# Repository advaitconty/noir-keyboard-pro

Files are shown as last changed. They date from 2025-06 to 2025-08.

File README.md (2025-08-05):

# Noir Keyboard Pro
A keyboard designed around the iPad Pro 11inch, mainly for use on the side

## Features
- Choc Red Pro switches that are hotswappable to your heart's content
- A simple design with extra pins if anything extra is required for a Pico
- A stabilizer-less design allowing for just nice uses

## BOM
*Prices in USD*

|Item |Quantity|Full Price|Remarks |Link |
|---|---|---|---|---|
|EVA foam |1 |$1.29 |Black variant 3mm 30x50  |https://www.lazada.sg/products/eva-foam-board-production-1-10mm-thick-foam-board-i2849696182-s19642596230.html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 |
|Rasperry Pi Pico H |1 |$15.52 | |https://www.lazada.sg/products/original-raspberry-pi-pico-2-pico-with-wireless-wifi-development-boardpico-or-pico-h-with-pin-header-support-mciropythonc-i3197404377-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 |
|Micro-USB to USB-C cable |1 |$3.87 | |https://www.lazada.sg/products/pdp-i1856449135-s9890909408.html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|
|Kailh Choc Red Pro Switches (v1) |100 |$41.15 |x90 piece |https://www.lazada.sg/products/kailh-low-profile-choc-switch-1350-rgb-for-keyboard-crystal-red-pro-pale-blue-pink-robin-silver-brown-white-yellow-orange-i3235755317-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 |
|Schotky Diodes |100 |$4.58 |x100 piece |https://www.lazada.sg/products/1n4148-do-35-small-signal-fast-switching-diode-i2668535659-s17380791247.html? |
|Kailh Choc Hotswap Socket |100 |$13.97 |x90 piece |https://www.lazada.sg/products/kailh-hot-swap-plug-socket-for-kailh-low-profile-switch-choc-1350-i3216869960-s21821088673.html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 |
|Noir Keyboard Pro PCB from JLCPCB |5 |$15.70 |Purchased |NA |
|128x32 OLED Screen |1 |$0.64 |White variant |https://www.lazada.sg/products/pdp-i3161600227-s21505742950.html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 |
|Shipping label |1 |$2.87 |For 3D printed parts |https://www.singpost.com/send-receive/sending-within-singapore/postage-paid-packaging/smartpac |
|Chisel tip for pinecil (my pinecil tip doesn't work - tried everything including steel wool)|1 |$8.58 |For my broken pinecil tip + getting D24 variant|https://www.lazada.sg/products/pine64-ts100-ts101-soldering-iron-tips-replacement-various-models-of-pinecil-v2-electric-soldering-iron-tip-ts-series-bc2-ils-k-i34779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 |
|Female headers for pico + display |2 |$1.46 |1x 20 pin + 1x 4 pin |https://www.lazada.sg//products/i2845738229-s19616005484.html?spm=a2o42.cart.0.0.732e7a93AmAcCy&urlFlag=true |
|Shipping Fees for everything |1 |$15 | |NA |

*Total: USD123.17 (SGD158.59)*

## Photos in CAD

*PCB*


*KiCad Schematic*


*Case design*


*Keycaps*


Full design of everything
---

## Credits
Massive kudos to @joe-scotto's ScottoKeebs repo (KiCad Footprints from the "Extras" folder, keyswitch design roughly taken from him)
Shapr3D and KiCad for their wonderful software

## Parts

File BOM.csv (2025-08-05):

Parts List (all prices in USD)
Total | $123.17
Ordering | Item | Quantity | Full Price | Remarks | Link
TRUE | EVA foam | 1 | $1.29 | Black variant 3mm 30x50 | https://www.lazada.sg/products/eva-foam-board-production-1-10mm-thick-foam-board-i2849696182-s19642596230.html
TRUE | Rasperry Pi Pico H | 1 | $15.52 |  | https://www.lazada.sg/products/original-raspberry-pi-pico-2-pico-with-wireless-wifi-development-boardpico-or-pico-h-with-pin-header-support-mciropythonc-i3197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
TRUE | Micro-USB to USB-C cable | 1 | $3.87 |  | https://www.lazada.sg/products/pdp-i1856449135-s9890909408.html?c=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
TRUE | Kailh Choc Red Pro Switches (v1) | 100 | $41.15 | x90 piece | https://www.lazada.sg/products/kailh-low-profile-choc-switch-1350-rgb-for-keyboard-crystal-red-pro-pale-blue-pink-robin-silver-brown-white-yellow-orange-i3235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
TRUE | Schotky Diodes | 100 | $4.58 | x100 piece | https://www.lazada.sg/products/1n4148-do-35-small-signal-fast-switching-diode-i2668535659-s17380791247.html
TRUE | Kailh Choc Hotswap Socket | 100 | $13.97 | x90 piece | https://www.lazada.sg/products/kailh-hot-swap-plug-socket-for-kailh-low-profile-switch-choc-1350-i3216869960-s21821088673.html
TRUE | Noir Keyboard Pro PCB from JLCPCB | 5 | $15.70 | Purchased | NA
TRUE | 128x32 OLED Screen | 1 | $0.64 | White variant | https://www.lazada.sg/products/pdp-i3161600227-s21505742950.html?c=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
TRUE | Shipping label | 1 | $2.87 | For 3D printed parts | https://www.singpost.com/send-receive/sending-within-singapore/postage-paid-packaging/smartpac
TRUE | Chisel tip for pinecil (my pinecil tip doesn't work - tried everything including steel wool) | 1 | $8.58 | For my broken pinecil tip + getting D24 variant | https://www.lazada.sg/products/pine64-ts100-ts101-soldering-iron-tips-replacement-various-models-of-pinecil-v2-electric-soldering-iron-tip-ts-series-bc2-ils-k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
TRUE | Female headers for pico + display | 2 | $1.46 | 1x 20 pin + 1x 4 pin | https://www.lazada.sg//products/i2845738229-s19616005484.html?urlFlag=true
TRUE | Shipping Fees for everything | 1 | $15 |  | NA

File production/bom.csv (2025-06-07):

Designator | Footprint | Quantity | Value | LCSC Part #
'"1, -_1, /1, 0)1, 1!1, 2@1, 3#1, 4$1, 5%1, 6^1, 7&1, 8*1, 9(1, ;:1, <,1, =+1, >.1, A1, B1, BACKSPACE1, BACKSPACE2, C1, CMD1, CMD2, CONTROL1, D1, DEL1, DEL2, DOWN1, E1, ENTER1, ESC1, F1, F10, F11, F12, F13, F2, F3, F4, F5, F6, F7, F8, F9, FN1, G1, H1, I1, J1, K1, L1, LEFT1, M1, N1, O1, OPTION1, P1, Q1, R1, RIGHT1, S1, SHIFT4, T1, U2, UP1, V1, W1, X1, Y1, Z1, [{1, ]}1, `~1 | Hotswap_Choc_V1_1.00u | 74 | Keyswitch
'"DIODE1, -_DIODE1, /?DIODE1, 0)DIODE1, 1!DIODE1, 2@DIODE1, 3#DIODE1, 4$DIODE1, 5%DIODE1, 6^DIODE1, 7&DIODE1, 8*DIODE1, 9(DIODE1, ;:DIODE1, <,DIODE1, =+DIODE1, >.DIODE1, ADIODE1, BACKSPACEDIODE1, BACKSPACEDIODE2, BDIODE1, CAPSLOCKDIODE1, CDIODE1, CMDDIODE1, CMDDIODE2, CONTROLDIODE1, DDIODE1, DELDIODE1, DELDIODE2, DOWNDIODE1, EDIODE1, ENTERDIODE1, ENTERDIODE2, ESCDIODE1, F10DIODE1, F11DIODE1, F12DIODE1, F1DIODE1, F2DIODE1, F3DIODE1, F4DIODE1, F5DIODE1, F6DIODE1, F7DIODE1, F8DIODE1, F9DIODE1, FDIODE1, FNDIODE1, GDIODE1, HDIODE1, IDIODE1, JDIODE1, KDIODE1, LDIODE1, LEFTDIODE1, MDIODE1, NDIODE1, ODIODE1, OPTIONDIODE1, PDIODE1, QDIODE1, RDIODE1, RIGHTDIODE1, SDIODE1, SHIFTDIODE1, SHIFTDIODE2, SHIFTDIODE3, SHIFTDIODE4, SPACEDIODE1, SPACEDIODE2, SPACEDIODE3, SPACEDIODE4, TABDIODE1, TDIODE1, UDIODE1, UPDIODE1, VDIODE1, WDIODE1, XDIODE1, YDIODE1, ZDIODE1, [{DIODE1, \|DIODE1, ]}DIODE1, `~DIODE1 | Diode_DO-35 | 85 | Diode
CAPSLOCK1 | Hotswap_Choc_V1_1.75u | 1 | Keyswitch
ENTER2, SHIFT1, SHIFT2 | Hotswap_Choc_V1_1.25u | 3 | Keyswitch
SHIFT3, SPACE1, SPACE2, SPACE3, SPACE4, TAB1, \|1 | Hotswap_Choc_V1_1.50u | 7 | Keyswitch
U1 | Raspberry_Pi_Pico | 1 | Raspberry_Pi_Pico

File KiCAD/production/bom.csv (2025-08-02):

Designator | Footprint | Quantity | Value | LCSC Part #
'"DIODE1, -_DIODE1, /?DIODE1, 0)DIODE1, 1!DIODE1, 2@DIODE1, 3#DIODE1, 4$DIODE1, 5%DIODE1, 6^DIODE1, 7&DIODE1, 8*DIODE1, 9(DIODE1, ;:DIODE1, <,DIODE1, =+DIODE1, >.DIODE1, ADIODE1, BACKSPACEDIODE1, BACKSPACEDIODE2, BDIODE1, CAPSLOCKDIODE1, CDIODE1, CMDDIODE1, CMDDIODE2, CONTROLDIODE1, DDIODE1, DELDIODE1, DELDIODE2, DOWNDIODE1, EDIODE1, ENTERDIODE1, ENTERDIODE2, ESCDIODE1, F10DIODE1, F11DIODE1, F12DIODE1, F1DIODE1, F2DIODE1, F3DIODE1, F4DIODE1, F5DIODE1, F6DIODE1, F7DIODE1, F8DIODE1, F9DIODE1, FDIODE1, FNDIODE1, GDIODE1, HDIODE1, IDIODE1, JDIODE1, KDIODE1, LDIODE1, LEFTDIODE1, MDIODE1, NDIODE1, ODIODE1, OPTIONDIODE1, PDIODE1, QDIODE1, RDIODE1, RIGHTDIODE1, SDIODE1, SHIFTDIODE1, SHIFTDIODE2, SHIFTDIODE3, SHIFTDIODE4, SPACEDIODE1, SPACEDIODE2, SPACEDIODE3, SPACEDIODE4, TABDIODE1, TDIODE1, UDIODE1, UPDIODE1, VDIODE1, WDIODE1, XDIODE1, YDIODE1, ZDIODE1, [{DIODE1, \|DIODE1, ]}DIODE1, `~DIODE1 | Diode_DO-35 | 85 | Diode
A, ALT/OPTION, ANGLE BRACKET, B, BACKSPACE, BLANK BACKSPACE, BLANK DELETE, BLANK ENTER, C, CHEVRON, CLOSED SQ. BRACKET, CONTROL, D, DASH, DELETE, DOWN ARROW, E, EIGHT, EQUALS, ESCAPE, F, F1, F10, F11, F12, F2, F3, F4, F5, F6, F7, F8, F9, FIVE, FOUR, FUNCTION, G, H, I, J, K, L, LEFT ARROW, M, N, NINE, O, ONE, OPEN SQ. BRACKET, P, Q, QUOTES, R, RIGHT, S, SEMI-COLON, SEVEN, SHIFT, SIX, SLASH, SUPER/COMMAND_2, SUPER/COMMAND, T, THREE, TILDE, TWO, U, UP ARROW, V, W, X, Y, Z, ZERO | Hotswap_Choc_V1_1.00u | 74 | Keyswitch
BACKSLASH, BLANK SHIFT, SPACE_4, SPACE_3, SPACE_2, SPACE, TAB | Hotswap_Choc_V1_1.50u | 7 | Keyswitch
BLANK SHIFT_2, ENTER, SHIFT_2 | Hotswap_Choc_V1_1.25u | 3 | Keyswitch
CAPS LOCK | Hotswap_Choc_V1_1.75u | 1 | Keyswitch
J2 | OLED_128x32 | 1 | OLED_128x32
U1 | Raspberry_Pi_Pico | 1 | Raspberry_Pi_Pico

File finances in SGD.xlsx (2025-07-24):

Parts List (all prices in SGD) |  | #VALUE!
Total | $104.32 | Budget: $191.58
Ordering | Item | Quantity | Price | Remarks | Link
TRUE | 5mm Thick EVA Foam | 1.00 | $3.90 |  | https://www.aliexpress.com/item/1005002621956105.html?mp=1
TRUE | Rasperry Pi Pico (With USB-C) | 1.00 | $2.88 |  | https://www.aliexpress.com/item/1005003371056277.html?mp=1
TRUE | Micro-USB to USB-C cable (in case Pico doesn't fit) | 1.00 | $2.50 |  | https://www.aliexpress.com/item/1005002361842974.html?mp=1
TRUE | Kailh Choc Red Pro Switches (v1) | 100.00 | $58.91 | Ordering x2 (1 90 piece, 1x 10 piece) | https://www.aliexpress.com/item/1005006626760418.html?mp=1
TRUE | Schotky Diodes | 100.00 | $1.31 | Sold in packs of 100 | https://www.aliexpress.com/item/1005008067721732.html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
TRUE | Kailh Choc Hotswap Socket | 100.00 | $7.05 | Sold in packs of 100 | https://www.aliexpress.com/item/1005006625852715.html?mp=1
TRUE | Noir Keyboard Pro PCB from JLCPCB | 5.00 | $27.77 | Sold in packs of 5, with shipping + new customer discount coupon | NA
FALSE | Silent Ambient Twilight Choc v1 Switches | 100.00 | $124.20 | Sold in packs of 10, considering between Choc Red Pros | https://ergokeyboard.sg/products/ambients-twilight-silent-linear-choc-switches
TRUE | 128x32 OLED Screen | 1.00 | $2.44 | White variant | https://www.aliexpress.com/item/1005006351390199.html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

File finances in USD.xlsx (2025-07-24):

Parts List (all prices in USD)
Total | $83.68
Ordering | Item | Quantity | Price | Remarks | Link
TRUE | 5mm Thick EVA Foam | 1.00 | $3.06 |  | https://www.aliexpress.com/item/1005002621956105.html?mp=1
TRUE | Rasperry Pi Pico (With USB-C) | 1.00 | $2.26 |  | https://www.aliexpress.com/item/1005003371056277.html?mp=1
TRUE | Micro-USB to USB-C cable (in case Pico doesn't fit) | 1.00 | $1.96 |  | https://www.aliexpress.com/item/1005002361842974.html?mp=1
TRUE | Kailh Choc Red Pro Switches (v1) | 100.00 | $46.16 | Ordering x2 (1 90 piece, 1x 10 piece) | https://www.aliexpress.com/item/1005006626760418.html?mp=1
TRUE | Schotky Diodes | 100.00 | $1.03 | Sold in packs of 100 | https://www.aliexpress.com/item/1005008067721732.html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
TRUE | Kailh Choc Hotswap Socket | 100.00 | $5.53 | Sold in packs of 100 | https://www.aliexpress.com/item/1005006625852715.html?mp=1
TRUE | Noir Keyboard Pro PCB from JLCPCB | 5.00 | $21.77 | Sold in packs of 5, with shipping + new customer discount coupon | NA
TRUE | 128x32 OLED Screen | 1.00 | $1.91 | White variant | https://www.aliexpress.com/item/1005006351390199.html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

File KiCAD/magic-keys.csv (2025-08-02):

Id | Designator | Footprint | Quantity | Designation | Supplier and ref
1 | Up1,Cmd1,Del1,Backspace1,'1,Option1,Q1,5%1,1!1,/1,-_1,F13,Control1,S1,F5,U2,6^1,Cmd2,H1,L1,E1,F6,B1,Enter1,Left1,M1, | :1,N1,F10,P1,F1,K1,7&1,<,1,`~1,=+1,F8,2@1,8*1,Backspace2,D1,3#1,Esc1,F2,Del2,T1,G1,X1,0)1,>.1,F4,F3,J1,Down1,O1,W1,9(1,V1,F9,C1,F7,A1,Right1,Fn1,[{1,I1,F11,Y1,R1,Shift4,F12,Z1,]}1,4$1" | Hotswap_Choc_V1_1.00u | 74 | Keyswitch
2 | J2 | OLED_128x32 | 1 | OLED_128x32
3 | Enter2,Shift1,Shift2 | Hotswap_Choc_V1_1.25u | 3 | Keyswitch
4 | U1 | Raspberry_Pi_Pico | 1 | Raspberry_Pi_Pico
5 | Space3,Tab1,Space4,Space1,\|1,Space2,Shift3 | Hotswap_Choc_V1_1.50u | 7 | Keyswitch
6 | CapsLock1 | Hotswap_Choc_V1_1.75u | 1 | Keyswitch
7 | IDiode1,>.Diode1,[{Diode1,`~Diode1,EnterDiode1,NDiode1,ShiftDiode3,=+Diode1,UDiode1,SpaceDiode1,QDiode1,1!Diode1,0)Diode1,PDiode1,DelDiode2,5%Diode1,SDiode1,SpaceDiode4,BackspaceDiode1,F9Diode1,EDiode1,ControlDiode1,ShiftDiode2,F10Diode1,F3Diode1,ShiftDiode1,EscDiode1,HDiode1,LDiode1,VDiode1,F6Diode1,KDiode1,BackspaceDiode2,TDiode1,MDiode1,F1Diode1,FnDiode1,ShiftDiode4,F7Diode1,XDiode1,WDiode1,DDiode1,9(Diode1,3#Diode1,6^Diode1,2@Diode1,F4Diode1,F12Diode1,F5Diode1,8*Diode1,/?Diode1,CmdDiode1,CapsLockDiode1,DownDiode1,LeftDiode1,F11Diode1,SpaceDiode2,UpDiode1,SpaceDiode3,DelDiode1,CmdDiode2,OptionDiode1,ODiode1,TabDiode1,ADiode1,4$Diode1,F2Diode1,RDiode1,'Diode1,YDiode1,EnterDiode2,GDiode1,<,Diode1,ZDiode1,JDiode1,F8Diode1,7&Diode1,RightDiode1,]}Diode1,FDiode1, | :Diode1,-_Diode1,BDiode1,CDiode1,\|Diode1" | Diode_DO-35 | 85 | Diode

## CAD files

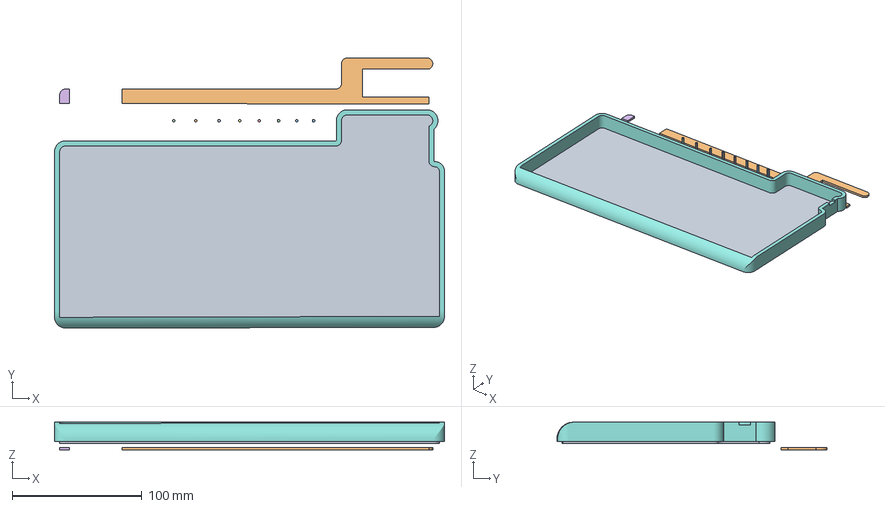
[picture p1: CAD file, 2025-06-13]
3D Files/Case/Print Ready Case.3mf
301.0 x 208.5 x 21.4 mm

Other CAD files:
3D Files/Full Design.step
3D Files/PCB.step

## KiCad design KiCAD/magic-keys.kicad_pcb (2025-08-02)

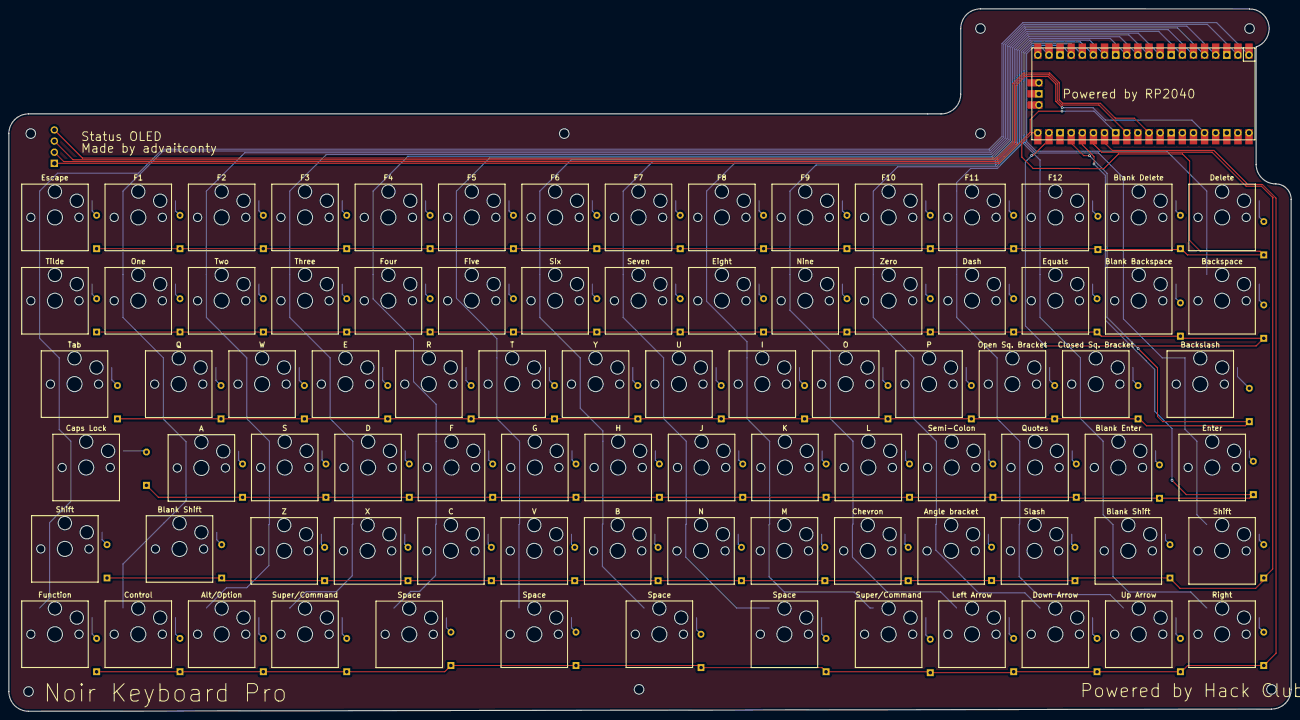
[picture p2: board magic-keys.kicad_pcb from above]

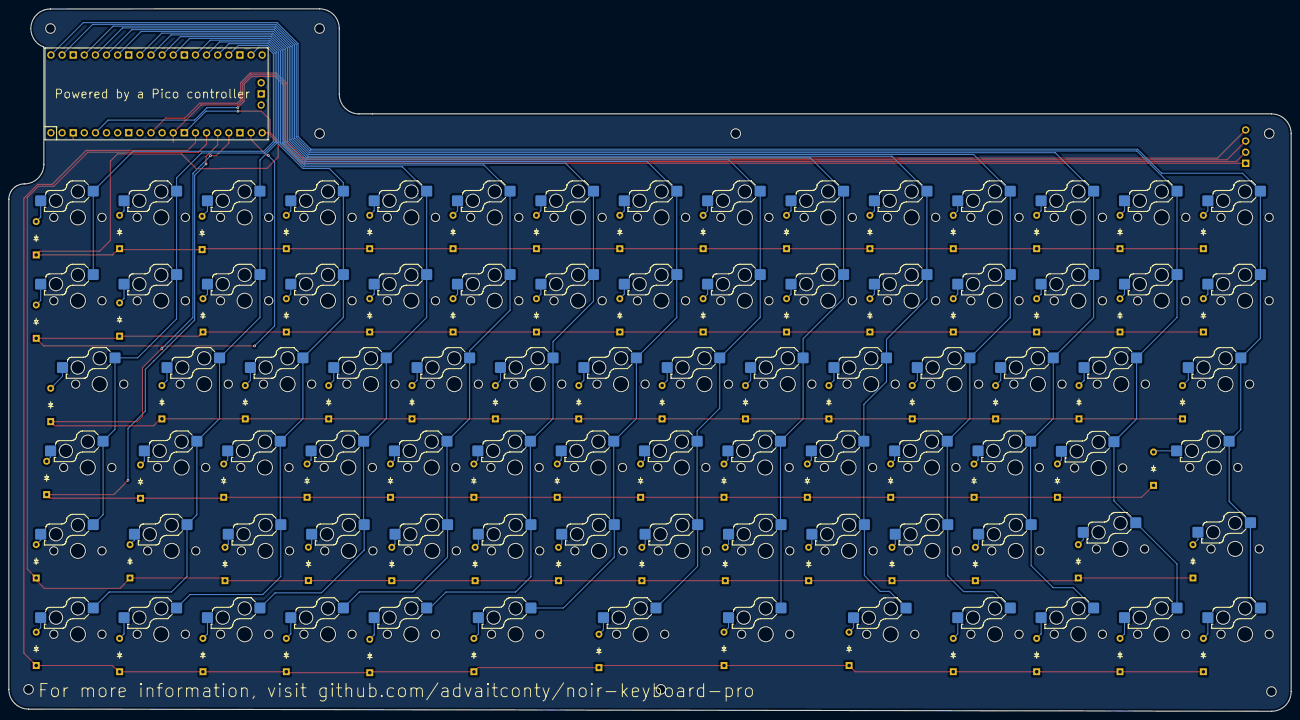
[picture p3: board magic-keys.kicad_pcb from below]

Board: 2 copper layers, 293.0 x 160.5 mm, 172 parts (85 on the bottom side), 110 nets.

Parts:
0)Diode1, 1!Diode1, 2@Diode1, 3#Diode1, 4$Diode1, 5%Diode1, 6^Diode1, 7&Diode1, 8*Diode1, 9(Diode1: Diode; Diode_DO-35
'"Diode1: Diode; Diode_DO-35
-_Diode1: Diode; Diode_DO-35
/?Diode1: Diode; Diode_DO-35
;:Diode1: Diode; Diode_DO-35
<,Diode1: Diode; Diode_DO-35
=+Diode1: Diode; Diode_DO-35
>.Diode1: Diode; Diode_DO-35
A: Keyswitch; Hotswap_Choc_V1_1.00u
ADiode1: Diode; Diode_DO-35
Alt/Option: Keyswitch; Hotswap_Choc_V1_1.00u
Angle bracket: Keyswitch; Hotswap_Choc_V1_1.00u
B: Keyswitch; Hotswap_Choc_V1_1.00u
BDiode1: Diode; Diode_DO-35
Backslash: Keyswitch; Hotswap_Choc_V1_1.50u
Backspace: Keyswitch; Hotswap_Choc_V1_1.00u
BackspaceDiode1, BackspaceDiode2: Diode; Diode_DO-35
Blank Backspace: Keyswitch; Hotswap_Choc_V1_1.00u
Blank Delete: Keyswitch; Hotswap_Choc_V1_1.00u
Blank Enter: Keyswitch; Hotswap_Choc_V1_1.00u
Blank Shift: Keyswitch; Hotswap_Choc_V1_1.25u
Blank Shift#2: Keyswitch; Hotswap_Choc_V1_1.50u
C: Keyswitch; Hotswap_Choc_V1_1.00u
CDiode1: Diode; Diode_DO-35
Caps Lock: Keyswitch; Hotswap_Choc_V1_1.75u
CapsLockDiode1: Diode; Diode_DO-35
Chevron: Keyswitch; Hotswap_Choc_V1_1.00u
Closed Sq. Bracket: Keyswitch; Hotswap_Choc_V1_1.00u
CmdDiode1, CmdDiode2: Diode; Diode_DO-35
Control: Keyswitch; Hotswap_Choc_V1_1.00u
ControlDiode1: Diode; Diode_DO-35
D: Keyswitch; Hotswap_Choc_V1_1.00u
DDiode1: Diode; Diode_DO-35
Dash: Keyswitch; Hotswap_Choc_V1_1.00u
DelDiode1, DelDiode2: Diode; Diode_DO-35
Delete: Keyswitch; Hotswap_Choc_V1_1.00u
Down Arrow: Keyswitch; Hotswap_Choc_V1_1.00u
DownDiode1: Diode; Diode_DO-35
E: Keyswitch; Hotswap_Choc_V1_1.00u
EDiode1: Diode; Diode_DO-35
Eight: Keyswitch; Hotswap_Choc_V1_1.00u
Enter: Keyswitch; Hotswap_Choc_V1_1.25u
EnterDiode1, EnterDiode2: Diode; Diode_DO-35
Equals: Keyswitch; Hotswap_Choc_V1_1.00u
EscDiode1: Diode; Diode_DO-35
Escape: Keyswitch; Hotswap_Choc_V1_1.00u
F, F1, F2, F3, F4, F5, F6, F7, F8, F9, F10, F11, F12: Keyswitch; Hotswap_Choc_V1_1.00u
F1Diode1, F2Diode1, F3Diode1, F4Diode1, F5Diode1, F6Diode1, F7Diode1, F8Diode1, F9Diode1, F10Diode1, F11Diode1, F12Diode1: Diode; Diode_DO-35
FDiode1: Diode; Diode_DO-35
Five: Keyswitch; Hotswap_Choc_V1_1.00u
FnDiode1: Diode; Diode_DO-35
Four: Keyswitch; Hotswap_Choc_V1_1.00u
Function: Keyswitch; Hotswap_Choc_V1_1.00u
G: Keyswitch; Hotswap_Choc_V1_1.00u
GDiode1: Diode; Diode_DO-35
H: Keyswitch; Hotswap_Choc_V1_1.00u
HDiode1: Diode; Diode_DO-35
I: Keyswitch; Hotswap_Choc_V1_1.00u
IDiode1: Diode; Diode_DO-35
J: Keyswitch; Hotswap_Choc_V1_1.00u
J2: OLED_128x32
JDiode1: Diode; Diode_DO-35
K: Keyswitch; Hotswap_Choc_V1_1.00u
KDiode1: Diode; Diode_DO-35
L: Keyswitch; Hotswap_Choc_V1_1.00u
LDiode1: Diode; Diode_DO-35
Left Arrow: Keyswitch; Hotswap_Choc_V1_1.00u
LeftDiode1: Diode; Diode_DO-35
M: Keyswitch; Hotswap_Choc_V1_1.00u
MDiode1: Diode; Diode_DO-35
N: Keyswitch; Hotswap_Choc_V1_1.00u
NDiode1: Diode; Diode_DO-35
Nine: Keyswitch; Hotswap_Choc_V1_1.00u
O: Keyswitch; Hotswap_Choc_V1_1.00u
ODiode1: Diode; Diode_DO-35
One: Keyswitch; Hotswap_Choc_V1_1.00u
Open Sq. Bracket: Keyswitch; Hotswap_Choc_V1_1.00u
OptionDiode1: Diode; Diode_DO-35
P: Keyswitch; Hotswap_Choc_V1_1.00u
PDiode1: Diode; Diode_DO-35
Q: Keyswitch; Hotswap_Choc_V1_1.00u
QDiode1: Diode; Diode_DO-35
Quotes: Keyswitch; Hotswap_Choc_V1_1.00u
R: Keyswitch; Hotswap_Choc_V1_1.00u
RDiode1: Diode; Diode_DO-35
Right: Keyswitch; Hotswap_Choc_V1_1.00u
RightDiode1: Diode; Diode_DO-35
S: Keyswitch; Hotswap_Choc_V1_1.00u
SDiode1: Diode; Diode_DO-35
Semi-Colon: Keyswitch; Hotswap_Choc_V1_1.00u
Seven: Keyswitch; Hotswap_Choc_V1_1.00u
Shift: Keyswitch; Hotswap_Choc_V1_1.25u
Shift#2: Keyswitch; Hotswap_Choc_V1_1.00u
ShiftDiode1, ShiftDiode2, ShiftDiode3, ShiftDiode4: Diode; Diode_DO-35
Six: Keyswitch; Hotswap_Choc_V1_1.00u
Slash: Keyswitch; Hotswap_Choc_V1_1.00u
Space: Keyswitch; Hotswap_Choc_V1_1.50u
Space#2, Space#3, Space#4: Keyswitch; Hotswap_Choc_V1_1.50u
SpaceDiode1, SpaceDiode2, SpaceDiode3, SpaceDiode4: Diode; Diode_DO-35
Super/Command: Keyswitch; Hotswap_Choc_V1_1.00u
Super/Command#2: Keyswitch; Hotswap_Choc_V1_1.00u
T: Keyswitch; Hotswap_Choc_V1_1.00u
TDiode1: Diode; Diode_DO-35
Tab: Keyswitch; Hotswap_Choc_V1_1.50u
TabDiode1: Diode; Diode_DO-35
Three: Keyswitch; Hotswap_Choc_V1_1.00u
Tilde: Keyswitch; Hotswap_Choc_V1_1.00u
Two: Keyswitch; Hotswap_Choc_V1_1.00u
U: Keyswitch; Hotswap_Choc_V1_1.00u
U1: Raspberry_Pi_Pico
UDiode1: Diode; Diode_DO-35
Up Arrow: Keyswitch; Hotswap_Choc_V1_1.00u
UpDiode1: Diode; Diode_DO-35
V: Keyswitch; Hotswap_Choc_V1_1.00u
VDiode1: Diode; Diode_DO-35
W: Keyswitch; Hotswap_Choc_V1_1.00u
WDiode1: Diode; Diode_DO-35
X: Keyswitch; Hotswap_Choc_V1_1.00u
XDiode1: Diode; Diode_DO-35
Y: Keyswitch; Hotswap_Choc_V1_1.00u
YDiode1: Diode; Diode_DO-35
Z: Keyswitch; Hotswap_Choc_V1_1.00u
ZDiode1: Diode; Diode_DO-35
Zero: Keyswitch; Hotswap_Choc_V1_1.00u
[{Diode1: Diode; Diode_DO-35
\|Diode1: Diode; Diode_DO-35
]}Diode1: Diode; Diode_DO-35
`~Diode1: Diode; Diode_DO-35

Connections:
Column 0: Caps Lock.1, Escape.1, Function.1, Shift.1, Tab.1, Tilde.1, U1.1 (GPIO0)
Column 1: A.1, Blank Shift#2.1, Control.1, F1.1, One.1, Q.1, U1.2 (GPIO1)
Column 2: Alt/Option.1, F2.1, S.1, Two.1, U1.4 (GPIO2), W.1, Z.1
Column 3: D.1, E.1, F3.1, Super/Command.1, Three.1, U1.5 (GPIO3), X.1
Column 4: C.1, F.1, F4.1, Four.1, R.1, Space#3.1, U1.6 (GPIO4)
Column 5: F5.1, Five.1, G.1, Space#4.1, T.1, U1.7 (GPIO5), V.1
Column 6: B.1, F6.1, H.1, Six.1, Space.1, U1.9 (GPIO6), Y.1
Column 7: F7.1, J.1, N.1, Seven.1, Space#2.1, U.1, U1.10 (GPIO7)
Column 8: Eight.1, F8.1, I.1, K.1, M.1, Super/Command#2.1, U1.11 (GPIO8)
Column 9: Chevron.1, F9.1, L.1, Left Arrow.1, Nine.1, O.1, U1.12 (GPIO9)
Column 10: Angle bracket.1, Down Arrow.1, F10.1, P.1, Semi-Colon.1, U1.14 (GPIO10), Zero.1
Column 11: Dash.1, F11.1, Open Sq. Bracket.1, Quotes.1, Slash.1, U1.15 (GPIO11), Up Arrow.1
Column 12: Blank Enter.1, Blank Shift.1, Closed Sq. Bracket.1, Equals.1, F12.1, Right.1, U1.16 (GPIO12)
Column 13: Backslash.1, Blank Backspace.1, Blank Delete.1, Enter.1, Shift#2.1, U1.17 (GPIO13)
Column 14: Backspace.1, Delete.1, U1.19 (GPIO14)
unnamed: 0)Diode1.2 (A), Zero.2
unnamed: 1!Diode1.2 (A), One.2
unnamed: 2@Diode1.2 (A), Two.2
unnamed: 3#Diode1.2 (A), Three.2
unnamed: 4$Diode1.2 (A), Four.2
unnamed: 5%Diode1.2 (A), Five.2
unnamed: 6^Diode1.2 (A), Six.2
unnamed: 7&Diode1.2 (A), Seven.2
unnamed: 8*Diode1.2 (A), Eight.2
unnamed: 9(Diode1.2 (A), Nine.2
unnamed: '"Diode1.2 (A), Quotes.2
unnamed: -_Diode1.2 (A), Dash.2
unnamed: /?Diode1.2 (A), Slash.2
unnamed: ;:Diode1.2 (A), Semi-Colon.2
unnamed: <,Diode1.2 (A), Chevron.2
unnamed: =+Diode1.2 (A), Equals.2
unnamed: >.Diode1.2 (A), Angle bracket.2
unnamed: A.2, ADiode1.2 (A)
unnamed: B.2, BDiode1.2 (A)
unnamed: BackspaceDiode1.2 (A), Blank Backspace.2
unnamed: Backspace.2, BackspaceDiode2.2 (A)
unnamed: C.2, CDiode1.2 (A)
unnamed: Caps Lock.2, CapsLockDiode1.2 (A)
unnamed: CmdDiode1.2 (A), Super/Command.2
unnamed: CmdDiode2.2 (A), Super/Command#2.2
unnamed: Control.2, ControlDiode1.2 (A)
unnamed: D.2, DDiode1.2 (A)
unnamed: Blank Delete.2, DelDiode1.2 (A)
unnamed: DelDiode2.2 (A), Delete.2
unnamed: Down Arrow.2, DownDiode1.2 (A)
unnamed: E.2, EDiode1.2 (A)
unnamed: Blank Enter.2, EnterDiode1.2 (A)
unnamed: Enter.2, EnterDiode2.2 (A)
unnamed: EscDiode1.2 (A), Escape.2
unnamed: F1.2, F1Diode1.2 (A)
unnamed: F2.2, F2Diode1.2 (A)
unnamed: F3.2, F3Diode1.2 (A)
unnamed: F4.2, F4Diode1.2 (A)
unnamed: F5.2, F5Diode1.2 (A)
unnamed: F6.2, F6Diode1.2 (A)
unnamed: F7.2, F7Diode1.2 (A)
unnamed: F8.2, F8Diode1.2 (A)
unnamed: F9.2, F9Diode1.2 (A)
unnamed: F10.2, F10Diode1.2 (A)
unnamed: F11.2, F11Diode1.2 (A)
unnamed: F12.2, F12Diode1.2 (A)
unnamed: F.2, FDiode1.2 (A)
unnamed: FnDiode1.2 (A), Function.2
unnamed: G.2, GDiode1.2 (A)
unnamed: H.2, HDiode1.2 (A)
unnamed: I.2, IDiode1.2 (A)
unnamed: J2.1 (GND), U1.28 (GND)
unnamed: J2.3 (SCL), U1.29 (GPIO22)
unnamed: J2.4 (SDA), U1.31 (GPIO26_ADC0)
unnamed: J2.2 (VCC), U1.36 (3V3)
unnamed: J.2, JDiode1.2 (A)
unnamed: K.2, KDiode1.2 (A)
unnamed: L.2, LDiode1.2 (A)
unnamed: Left Arrow.2, LeftDiode1.2 (A)
unnamed: M.2, MDiode1.2 (A)
unnamed: N.2, NDiode1.2 (A)
unnamed: O.2, ODiode1.2 (A)
unnamed: Alt/Option.2, OptionDiode1.2 (A)
unnamed: P.2, PDiode1.2 (A)
unnamed: Q.2, QDiode1.2 (A)
unnamed: R.2, RDiode1.2 (A)
unnamed: Right.2, RightDiode1.2 (A)
unnamed: S.2, SDiode1.2 (A)
unnamed: Shift.2, ShiftDiode1.2 (A)
unnamed: Blank Shift.2, ShiftDiode2.2 (A)
unnamed: Blank Shift#2.2, ShiftDiode3.2 (A)
unnamed: Shift#2.2, ShiftDiode4.2 (A)
unnamed: Space#3.2, SpaceDiode1.2 (A)
unnamed: Space#4.2, SpaceDiode2.2 (A)
unnamed: Space.2, SpaceDiode3.2 (A)
unnamed: Space#2.2, SpaceDiode4.2 (A)
unnamed: T.2, TDiode1.2 (A)
unnamed: Tab.2, TabDiode1.2 (A)
unnamed: U.2, UDiode1.2 (A)
unnamed: Up Arrow.2, UpDiode1.2 (A)
unnamed: V.2, VDiode1.2 (A)
unnamed: W.2, WDiode1.2 (A)
unnamed: X.2, XDiode1.2 (A)
unnamed: Y.2, YDiode1.2 (A)
unnamed: Z.2, ZDiode1.2 (A)
unnamed: Open Sq. Bracket.2, [{Diode1.2 (A)
unnamed: Backslash.2, \|Diode1.2 (A)
unnamed: Closed Sq. Bracket.2, ]}Diode1.2 (A)
unnamed: Tilde.2, `~Diode1.2 (A)
Row 0: DelDiode1.1 (K), DelDiode2.1 (K), EscDiode1.1 (K), F1Diode1.1 (K), F2Diode1.1 (K), F3Diode1.1 (K), F4Diode1.1 (K), F5Diode1.1 (K), F6Diode1.1 (K), F7Diode1.1 (K), F8Diode1.1 (K), F9Diode1.1 (K), F10Diode1.1 (K), F11Diode1.1 (K), F12Diode1.1 (K), U1.21 (GPIO16)
Row 1: 0)Diode1.1 (K), 1!Diode1.1 (K), 2@Diode1.1 (K), 3#Diode1.1 (K), 4$Diode1.1 (K), 5%Diode1.1 (K), 6^Diode1.1 (K), 7&Diode1.1 (K), 8*Diode1.1 (K), 9(Diode1.1 (K), -_Diode1.1 (K), =+Diode1.1 (K), BackspaceDiode1.1 (K), BackspaceDiode2.1 (K), U1.22 (GPIO17), `~Diode1.1 (K)
Row 2: EDiode1.1 (K), IDiode1.1 (K), ODiode1.1 (K), PDiode1.1 (K), QDiode1.1 (K), RDiode1.1 (K), TDiode1.1 (K), TabDiode1.1 (K), U1.24 (GPIO18), UDiode1.1 (K), WDiode1.1 (K), YDiode1.1 (K), [{Diode1.1 (K), \|Diode1.1 (K), ]}Diode1.1 (K)
Row 3: '"Diode1.1 (K), ;:Diode1.1 (K), ADiode1.1 (K), CapsLockDiode1.1 (K), DDiode1.1 (K), EnterDiode1.1 (K), EnterDiode2.1 (K), FDiode1.1 (K), GDiode1.1 (K), HDiode1.1 (K), JDiode1.1 (K), KDiode1.1 (K), LDiode1.1 (K), SDiode1.1 (K), U1.25 (GPIO19)
Row 4: /?Diode1.1 (K), <,Diode1.1 (K), >.Diode1.1 (K), BDiode1.1 (K), CDiode1.1 (K), MDiode1.1 (K), NDiode1.1 (K), ShiftDiode1.1 (K), ShiftDiode2.1 (K), ShiftDiode3.1 (K), ShiftDiode4.1 (K), U1.26 (GPIO20), VDiode1.1 (K), XDiode1.1 (K), ZDiode1.1 (K)
Row 5: CmdDiode1.1 (K), CmdDiode2.1 (K), ControlDiode1.1 (K), DownDiode1.1 (K), FnDiode1.1 (K), LeftDiode1.1 (K), OptionDiode1.1 (K), RightDiode1.1 (K), SpaceDiode1.1 (K), SpaceDiode2.1 (K), SpaceDiode3.1 (K), SpaceDiode4.1 (K), U1.27 (GPIO21), UpDiode1.1 (K)

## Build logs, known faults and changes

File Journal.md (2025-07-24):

---
title: "Noir Keyboard Pro"
author: "advaitconty"
description: "A mechanical Keyboard designed specificallly for use with the iPad Pro M1/M2 11inch (probably works with the new Pro M4 and maybe the new design Air 11inch)"
created_at: "2025-06-06"
---

# Journal
**Total time spent: 22 hours**

## Day 1: 6th Jun Friday
*Hours spent: 3h 30min*
Was getting fustrated on my iPad for not having a decent keyboard (am on a Logitech Slim Folio Pro currently) and wanted something better so decided to take part in Highway to make a keyboard my huge hands can use

Started by watching this [Wonderful tutorial by ScottoKeebs](https://www.youtube.com/watch?v=8WXpGTIbxlQ&t=1052s) on how to get started and learnt a bit about KiCAD

Followed his tutorial and messed around a bit more to understand the idea of a macropad


Did some research and decided on this layout! Connects to the iPad via a Pi Pico using Type C (planning on using my own Orpheus Pico to connect it) and created a rough schematic

Decided on the keyswitches to be the Kailh Choc v1 for not being too loud that I can't use it in a classroom but slim enough that I can make it into a way for me to store my iPad.

I so wasn't expecting this to be insanely easy?? HOW IS A KEYBOARD THIS EASY?? (i think imma rage when it comes to figuring out the QMK stuff for this keyboard and working with Shapr3d but that should be probably fine on my iPad)

Was planning on using the Choc v1 switches for lower profiles however choose to use universal Choc v1/v2 ports on my keyboard so I can switch anytime and also be able to use MX keycaps

First row be takin 3 centuries vrooo 😭

HOW DID I NOT KNOW THAT SELECTING A PART IN A SCHEMATIC SELECTS IT IN THE PCB EDITOR THAT IS GOATED YOOOOOO

KiCAD Snapping feels weird (that's why dropping keys in takes sooooo long)

### Reasons why I didn't want a macropad
1. Kinda useless (for someone who is on iPad all the time, would rather have to use a keyboard shortcut I'm familiar with)
2. I can develop a case around this!

3hours and 3 minutes of learning KiCad and making my own custom keyboard and fiddling around with different sizing, here is the final design (haven't even but in the diodes yet :sob:)



---

## Day 2: 7th Jun Saturday
*hours spent: 2h 33min*
*Doing this journal a day late because I was too lazy to do it yesterday*

So today I did some research on stabilizers, and found out that my best (albeit sketchy) bet was to use some random ones of AliExpress, and then spent literally 1 WHOLE HOUR TRYING TO FIND FOOTPRINTS FOR IT

It drove me mentally insane, and eventually I just gave up. Instead, I did some research and found out there is a way to use 4 1.5u keys instead of 1 6u key for the spacebar and I have done that

Did some budgeting after I finished wiring up the v2 PCB schematic and then PCB. Gonna add some spinny thing later tommorow for volume control (maybe)

The new schematic design looks great, only complaint is how the spacebar and shift keys had to be wired 😭


*Schematic*


*PCB*

Notice how bad the tracks are all over the place at the bottom, this was ALL BECAUSE of my LAZINESS

---
## Day 3: 8th Jun Sunday
*Hours spent: 4h*

So my laziness bit me again today, I realised that many pads were shorting, the Pi wasn't jutting out to plug in a cable, and most importantly no standoffs to keep the keyboards in place, kinda impressive I messed up so much lol

So I redid it, so it's much cleaner now!


*Clean PCB*


*PCB before board shape change*


*PCB schematic updated*

After this, choose to learn some Shapr3d, and I messed around with some Choc keys templates from Scottokeebs (unfortuantely forgot to take screenshots on this)

and then I worked on redesigning the PCB cuts so it is better and has mount points


*Redesigned PCB*

and that was Sunday!

---
## Day 4: 9th Jun Monday
*Hours spent: 3h*

Today I didn't want to do much, instead just worked on creating the case today in Shapr3D



Added a nice incline on the front so my hands don't die when typing on it, albeit not very long, and also added some plastic studs on the side (as seen in the image) that I will hot-glue when the PCB comes

Eh guess I got bored in the evening, decided to work on the keycaps (just so I have hope of getting the Silent Ambient Twilight keyswitches in terms of funds)

Modelled up all the odd-sized keys/keys with symbols 


Went the embossed route for this just so I don't have to paint it over and I can still read it without it causing much issues (also my fingers can literally feel the keys)

Used @scottokeebs' Choc keys template layout and it is modelled very well, might be able to finish by tmw, or might spend the whole day watching WWDC highlights lol (let's see what happens tmw)

---
## Day 5: 10th Jun Tuesday
*Hours spent: 1h*

Ok kinda slacked today due to WWDC highlights and messing around with Liquid Glass (iPadOS is soooo good now) but just worked on the keycaps and got all the special keys + started on the actual QWERTY keys



Nothing much other then that. Decided on using the Monaspace Neon font just because of how nice it looks + its a monospace font

---
## Day 6: 11th Jun Wednesday
*Hours spent: 3h 30min*

Spent sooo much just because I HAVE A CLEAR CHANCE OF FINISHING THE PROJECT (maybe tommorow morning just because I forgot about firmware lol)



I finished the case, keeping a kind of bare PCB aesthetic (now I anyways have more budget to get a black PCB)

I also finalised the parts list today



After the stabilizer-less conundrum, I found out it needs 99 keys??? So guess I'm getting 100 keys because no one actually sells keys in packs of 1.

Anyways after that I worked on finishing most of the keys, gonna finish everything else tommorow in the morning

*My bad the one thing I forgot to take a screenshot of-*

---
## Day 7: 12th Jun Thursday
*Hours spent: 4h 30min*

One week later, I have finally completed this! So this day I finished up the keycaps, checked on the wiring to make sure no issues, and started on the QMK code



After some research, I found that KMK is more user-friendly so I chose to work on that instead

I finished the firmware after messing around with my Pi Pico from my Sprig and it seems to work!

That was the end of this!

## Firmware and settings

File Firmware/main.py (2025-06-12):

import board
from kmk.kmk_keyboard import KMKKeyboard
from kmk.keys import KC
from kmk.modules.layers import Layers
from kmk.extensions.media_keys import MediaKeys

keyboard = KMKKeyboard()

keyboard.col_pins = (board.GP0, board.GP1, board.GP2, board.GP3, board.GP4, board.GP5, board.GP6, board.GP7, board.GP8, board.GP9, board.GP10, board.GP11, board.GP12, board.GP13)
keyboard.row_pins = (board.GP14, board.GP15, board.GP16, board.GP17, board.GP18, board.GP19)
keyboard.diode_orientation = "COL2ROW"  

keyboard.modules.append(Layers(keyboard))
keyboard.extensions.append(MediaKeys())

BASE = 0
IPAD_LAYER = 1

keyboard.keymap = [
    [
        KC.ESC,    KC.N1,    KC.N2,    KC.N3,    KC.N4,    KC.N5,    KC.N6,    KC.N7,    KC.N8,    KC.N9,    KC.N0,    KC.MINS,   KC.EQL,    KC.BSPC,
        KC.TAB,    KC.Q,     KC.W,     KC.E,     KC.R,     KC.T,     KC.Y,     KC.U,     KC.I,     KC.O,     KC.P,     KC.LBRC,   KC.RBRC,   KC.BSLS,
        KC.CAPS,   KC.A,     KC.S,     KC.D,     KC.F,     KC.G,     KC.H,     KC.J,     KC.K,     KC.L,     KC.SCLN,  KC.QUOT,   KC.ENT,
        KC.LSFT,   KC.Z,     KC.X,     KC.C,     KC.V,     KC.B,     KC.N,     KC.M,     KC.COMM,  KC.DOT,   KC.SLSH,  KC.RSFT,   KC.UP,     KC.DEL,
        KC.LCTL,   KC.LALT,  KC.LGUI,  KC.SPACE, KC.SPACE, KC.SPACE, KC.RGUI,  KC.RALT,  KC.TO(IPAD_LAYER),  KC.LEFT,  KC.DOWN,  KC.RGHT,
        KC.F1,     KC.F2,    KC.F3,    KC.F4,    KC.F5,    KC.F6,    KC.F7,    KC.F8,    KC.F9,    KC.F10,   KC.F11,   KC.F12,
    ],
    
    [
        KC.TO(BASE), KC.BRIGHTNESS_DOWN, KC.BRIGHTNESS_UP, KC.NO, KC.NO, KC.NO, KC.NO, KC.MEDIA_PREV_TRACK, KC.MEDIA_PLAY_PAUSE, KC.MEDIA_NEXT_TRACK, KC.MUTE, KC.VOLD, KC.VOLU, KC.NO,
        KC.LGUI(KC.TAB), KC.NO, KC.LGUI(KC.W), KC.NO, KC.LGUI(KC.R), KC.LGUI(KC.T), KC.NO, KC.NO, KC.NO, KC.NO, KC.NO, KC.NO, KC.NO, KC.NO,
        KC.CAPS, KC.LGUI(KC.A), KC.LGUI(KC.S), KC.NO, KC.LGUI(KC.F), KC.NO, KC.LGUI(KC.H), KC.NO, KC.NO, KC.NO, KC.NO, KC.NO, KC.ENT,
        KC.LSFT, KC.LGUI(KC.LSFT(KC.Z)), KC.NO, KC.LGUI(KC.C), KC.LGUI(KC.V), KC.NO, KC.LGUI(KC.N), KC.NO, KC.NO, KC.NO, KC.NO, KC.RSFT, KC.UP, KC.DEL,
        KC.LCTL, KC.LALT, KC.LGUI, KC.LGUI(KC.SPACE), KC.LGUI(KC.SPACE), KC.LGUI(KC.SPACE), KC.RGUI, KC.RALT, KC.TO(BASE), KC.LEFT, KC.DOWN, KC.RGHT,
        KC.NO, KC.NO, KC.LGUI(KC.LSFT(KC.N3)), KC.LGUI(KC.LSFT(KC.N4)), KC.NO, KC.NO, KC.NO, KC.NO, KC.NO, KC.NO, KC.LGUI(KC.PLUS), KC.LGUI(KC.MINS),
    ],
]


keyboard.go()

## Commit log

2025-06-06 added my first keyboard attempt! (didn't add the tutorial stuff tho)
    [magic-keys.kicad_pcb, magic-keys.kicad_sch]
2025-06-06 added journal, added readme, refactored files
    [magic-keys.kicad_pcb, magic-keys.kicad_sch]
2025-06-06 added more stuff for magickeys
    [magic-keys.kicad_pcb, magic-keys.kicad_sch]
2025-06-07 changed layout for stabs (to be keys), finished schematics
    [bom.csv, designators.csv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]
2025-06-08 Optimised wiring
    [magic-keys.csv, magic-keys.kicad_pcb, magic-keys.kicad_sch]
2025-06-09 added mount pounts, added case
    [case-final.3mf, magic-keys.kicad_pcb, magic-keys.kicad_sch]
2025-06-09 forgot to commit updated PCB
    [magic-keys.kicad_pcb]
2025-06-09 added keycaps design
    [NoirKeyboardProCase.3mf, case-final.3mf]
2025-06-11 Updated files
    [NoirKeyboardProCase.3mf, Print Ready Case.3mf, bom.csv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]
2025-06-11 Removed BOM
    [magic-keys.csv]
2025-06-12 added final files
    [bom.csv, designators.csv, positions.csv]
2025-06-12 added finances
    [finances.xlsx]
2025-06-13 added OLED screengit status
    [Print Ready Case.3mf, magic-keys.kicad_pcb, magic-keys.kicad_sch]
2025-06-13 modify finances
    [finances.xlsx]
2025-06-26 addded STEP for PCB case
    [Full Design.step, PCB.step]
2025-07-04 added STEP CADs of full PCB
2025-07-04 Added BOM
    [BOM.csv]
2025-07-24 edited for review
    [BOM.csv, bom.csv, designators.csv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]
2025-07-30 added a stuff i missed out
    [BOM.csv, finances in SGD.csv, finances.csv]
2025-08-02 updated BOM, retraced PCB for a nicer thing
    [BOM.csv, bom.csv, designators.csv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]
2025-08-02 added pinecil tip
    [BOM.csv]
2025-08-05 updated BOM, sending for final re-review after updating images
    [BOM.csv]
